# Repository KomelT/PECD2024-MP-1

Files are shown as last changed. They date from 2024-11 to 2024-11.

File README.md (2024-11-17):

# PECD2024-MP-1

Project for class PECD (Programming energy constrained devices), at FRI, University of Ljubljana.

## Running

### Server

```bash
cd server

docker compose build

docker compose up -d
```

### App

```bash
raspi-config # enable SPI under Interface Options > SPI

cd app

nano main.py # edit server address

cp planter.service /etc/systemd/system/planter.service

apt install python3-pip python3-picamera2 -y

pip3 install -r requirements.txt

systemctl enable planter.service

systemctl start planter.service
```

## Wiring

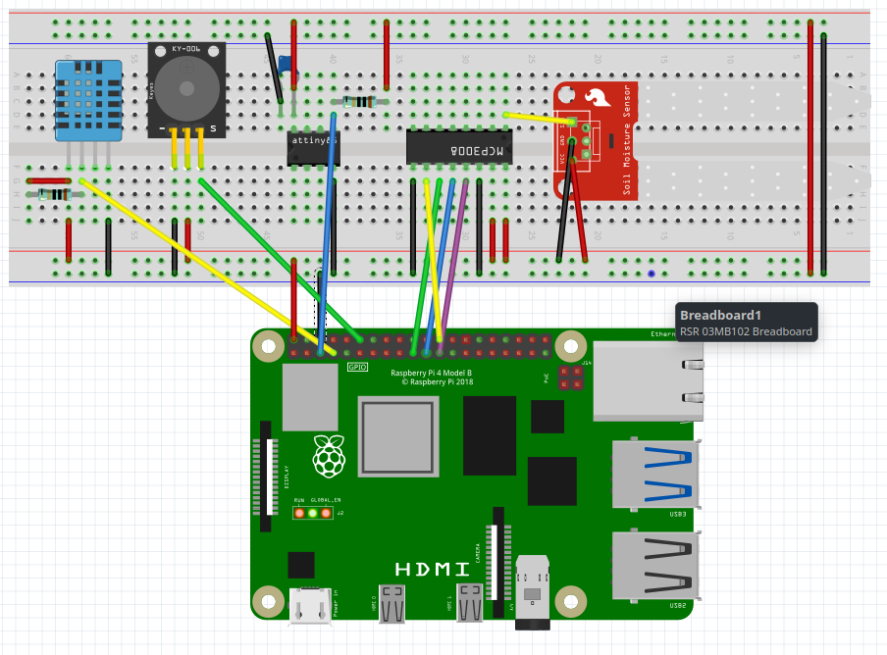
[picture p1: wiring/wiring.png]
Wiring diagram


## [Raspberry PI energy saving](./energy_saving/README.md)

## Disclaimer

### This app was created for educational purposes only, don't use the app or any code from the app in real life!! Creators aren't liable for any damages done by using code from this repository.

## Authors

- Tilen Komel
- Telmo Sendino Sainz

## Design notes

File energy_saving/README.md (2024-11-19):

# Energy saving

## What we can do?

**Using simple OS**
- Raspberry PI OS Lite
- Alpine Linux

**Disabe 3 cores**
- Adding `maxcpus=1` into `/boot/firmware/cmdline.txt`

**Clock Down the CPU**
- Setting CPU to "preset": `"powersave"| sudo tee /sys/devices/system/cpu/cpu0/cpufreq/scaling_governor`
  OR
- Manually specifaying frequency, appending code below into `/boot/firmware/config.txt`:

```
[all]
arm_freq=900
arm_freq_max=900
```

**Disable USB controller**
- `echo '1-1' |sudo tee /sys/bus/usb/drivers/usb/unbind`

**Disable Wi-Fi**\
Add code bellow into `/boot/firmware/config.txt`:

```bash
[all]
dtoverlay=disable-wifi
```

**Disable Bluetooth**\
Add code bellow into `/boot/firmware/config.txt`:

```bash
[all]
dtoverlay=disable-bt
```

**Disable HDMI**
- `vcgencmd display_power 0 3 %% vcgencmd display_power 0 7`

**Disable RJ45 port**
- `ip link set eth0 down`

**Disable Onboard LEDs**\
Add code bellow into `/boot/firmware/config.txt`:

```bash
[pi4]
# Disable the PWR LED
dtparam=pwr_led_trigger=none
dtparam=pwr_led_activelow=off
# Disable the Activity LED
dtparam=act_led_trigger=none
dtparam=act_led_activelow=off
# Disable ethernet port LEDs
dtparam=eth_led0=4
dtparam=eth_led1=4
```

**Disabling WAKE_ON_GPIO**\
Edit `WAKE_ON_GPIO` to `0`, with `rpi-eeprom-config --edit`.

## What does the numbers say?

**OS**\
We have performed the test with 3 different OSes. Power draw was mesaured 3 minutes after boot for 50s with enabled Wi-Fi.

- Alpine Linux 1827.28 mW
- Raspberry PI OS 1795.26 mW
- Raspberry PI Lite 1774.07 mW

Consclusion: We thought Alpine Linux will perform the best, but it actually didn't. We will use Raspberry PI Lite for other test and for final product.

**Cores**\
Again power was mesaured 3 minutes after boot for 50s with enabled Wi-Fi, but this time with only one core enabled.

Power usage was: 1705.58 mW, which isn't signiicant power optimization, but let them disabled for now.

**Underclocking**\
While idling the power usage was 1505.35 mW, which is an improvement.

**USB**\
We tried to disable USBs, but it didnt made difference, with power usage, so we left USBs enabled.

**Bluetooth**\
Same was with Bluetooth. We didn't saw a difference.

**HDMI**\
Same was with HDMI. We didn't saw a difference.

**Onboard LEDs**\
Same was with LEDs. They use so small amount of power that we didn't saw a difference.

**Peripherals**\
With sensor / buzzer / ADC just plugged it we didn't notice any biger power draw.

**ATtiny85**\
We mesaured it by itself and it used 43 mW.

**Optimizing power off**\
When RPI is powered down with default settings it uses: __ mW\
But if we edit `WAKE_ON_GPIO` it uses: __ mW

## Resources

- https://ucilnica.fri.uni-lj.si/mod/page/view.php?id=53513
- https://blues.com/blog/tips-tricks-optimizing-raspberry-pi-power/
- https://stackoverflow.com/questions/23487728/ethernet-disabling-in-raspberry-pi#answer-23530711
- https://raspberrypi.stackexchange.com/questions/104944/rpi-4-consumes-2-5w-when-shut-down#128100

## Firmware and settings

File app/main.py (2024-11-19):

from argparse import ArgumentParser
from state import State
from parser import Parser
from buzzer import Buzzer
from sensors import Sensors
from camera import Camera
from RPi import GPIO
from time import sleep
from logs import log_event, is_daylight

parser = ArgumentParser(
    prog="Planter",
    description="Project for class PECD (Programming energy constrained devices), at FRI, University of Ljubljana.",
)

parser.add_argument(
    "--service",
    help="Tell program that is called from systemd service",
    action="store_true",
)

args = parser.parse_args()

print("[INFO] Starting main.py")

# GPIO mode is set to BCM, because of adafruit_dht library
# What? https://raspi.tv/2013/rpi-gpio-basics-4-setting-up-rpi-gpio-numbering-systems-and-inputs

LOCAL_MODE = False  # Set to True if you want to do plant recognition locally
THRESHOLD = 0.9

# Init State
state = State()
if not state.halted and args.service:
    print("[INFO] Exiting because not waking from halted state")
    exit(0)

if not is_daylight():
    print("[INFO] Not daylight, exiting")
    state.halt()

# Init Parser
parser = Parser()
parser.read_conf()

# Init Buzzer
buzzer = Buzzer()

s = Sensors()

# buzz once if the air humidit
# will buzz twice if air temperature
# and will buzz three times in case the soil humidity drops
air_temp, air_humid = s.read_temp_humid()
print(f"[INFO] Temp: {air_temp} Humid: {air_humid}")
soil_humid = s.read_soil_humid()
print(f"[INFO] Soil humid: {soil_humid}")

air_humid_out_range = not parser.in_range_air_humid(air_humid)
print(f"[INFO] Air humid out of range: {air_humid_out_range}")
air_temp_out_range = not parser.in_range_air_temp(air_temp)
print(f"[INFO] Air temp out of range: {air_temp_out_range}")
soil_humid_out_range = not parser.in_range_soil_humid(soil_humid)
print(f"[INFO] Soil humid out of range: {soil_humid_out_range}")

if air_humid_out_range:
    buzzer.buzz_x_times(1)
    sleep(1)

if air_temp_out_range:
    buzzer.buzz_x_times(2)
    sleep(1)

if soil_humid_out_range:
    buzzer.buzz_x_times(3)

# The condition is: ((some value out of range) and is daylight) or first_wake_up
take_pic = (
    air_humid_out_range or air_temp_out_range or soil_humid_out_range
) or state.waking_up

print(f"[INFO] Take pic: {take_pic}")

if take_pic:
    # Init Camera
    cam = Camera(sever_address="http://trojan:5000/process", local_mode=LOCAL_MODE)
    percentage = cam.get_percentage()
    plant_yellow_percentage = percentage["yellow_percentage"]
    plant_black_percentage = percentage["black_percentage"]
    log_event(
        f"camera has taken a pic: black={plant_black_percentage}% , yellow={plant_yellow_percentage}%"
    )

    if state.waking_up:
        state.set_plant_yellow_black_percentage(
            plant_yellow_percentage, plant_black_percentage
        )
    else:
        if plant_yellow_percentage > (state.plant_yellow_percentage + THRESHOLD):
            buzzer.buzz_x_times(4)
        if plant_black_percentage > (state.plant_black_percentage + THRESHOLD):
            buzzer.buzz_x_times(5)

# Clean GPIO before exit
GPIO.cleanup()

state.dump_state()
print("[INFO] Exiting main.py")
state.halt()

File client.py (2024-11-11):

import socket
import numpy as np
from io import BytesIO

PORT = 40007


def get_size(buf):
    header = buf[:4].decode()
    if header=='SIZE':
        size = int.from_bytes(buf[5:9],byteorder='little') 
        return size
    print('something was wrong while decoding the size from the header')
    raise RuntimeError

# pic must be bytes
def remove_bg_send(pic, dir_serv,size):
    s = socket.socket( socket.AF_INET, socket.SOCK_STREAM )
    s.connect((dir_serv,PORT) )
    dt = np.uint8

    while True:
        if not pic:
            print("Image is empty")
            break
        size_b =  int.to_bytes(size,4,byteorder='little')  
        
        s.sendall(b'SIZE ' + size_b + b' '+ pic)
        print(f"Image sended ( {size} bytes )")

        cont = 0
        # first block and size
        buf = s.recv(256)
        cont += len(buf)
        size = get_size(buf)
           
        processed_pic = buf[10:]
        while cont < size:
            buf = s.recv(4096)
            processed_pic += buf
            cont += len(buf)
        return (processed_pic)
    s.close()
 
    
if __name__ == "__main__":
    with open("../foto.jpg", "rb") as fd:
        pic = BytesIO(fd.read()).getvalue()
    
    size = len(pic)
    output_bytes = remove_bg_send(pic,"127.0.0.1",size)
    
    with open("output_main.png", "wb") as f:
        f.write(output_bytes)
    

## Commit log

2024-10-28 Add Sensors
    [configuration.txt]
2024-10-30 Refactor Sensors class to improve readability and add support for reading soil humidity
2024-10-30 Refactor main.py to initialize buzzer and sensors, and add temperature and humidity reading
    [main.py]
2024-10-30 Add log air temperature and humidity readings
2024-11-04 Updated soil sensor to wiring
2024-11-05 Add wiring
    [wiring.fzz]
2024-11-05 Add wiring diagram to readme
2024-11-11 implementing image procesing in the server, changes in the api and camera configuration
2024-11-12 Structure change
    [configuration.txt, wiring.fzz]
2024-11-13 Simplified camera code
2024-11-13 Add attiny
    [wiring.fzz]
2024-11-15 Add enable SPI
2024-11-15 Update power savings
2024-11-17 Format & cleanup
    [wiring.fzz]
2024-11-17 Update camera
2024-11-17 Fix camera process
